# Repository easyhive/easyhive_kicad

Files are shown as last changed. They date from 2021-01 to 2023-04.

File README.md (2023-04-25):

# easyhive_kicad
KiCAD Design Files for easyhive PCB

1. Branch (master): Design with Nb-IoT Modul from ublox (SARA N310)
2. Branch: Design with Nb-IoT Modul from Quectel (BC66 04 Std)

Notes for Generate the bom of material:
1. copy file "easyhive_bom.py" to your local KiCad Plugin folder
e.g. /usr/share/kicad/plugins
2. Open Eeschema
3. Tools -> Generate Bill of Material: add a new plugin (choose easyhive_bom.py)
4. Generate BOM! Path is your KiCad project directory

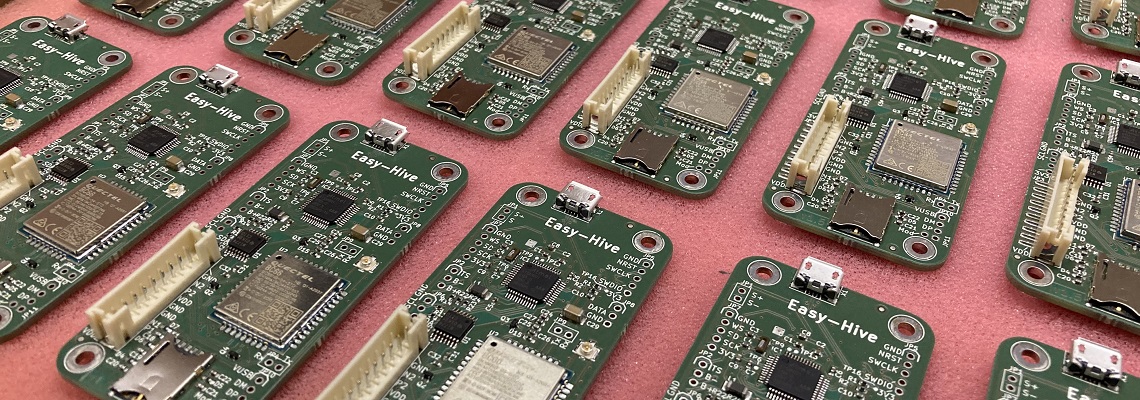
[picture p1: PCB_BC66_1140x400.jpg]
'easyhive PCB board version 1.5'


### copyright
Software: GPL 3.0 and following versions   
Hardware: CERN OHL 1.2 and following versions   
   
This files are distributed in the hope that it will be useful,
but WITHOUT ANY WARRANTY; without even the implied warranty of
MERCHANTABILITY or FITNESS FOR A PARTICULAR PURPOSE.
See the GNU General Public License for more details.

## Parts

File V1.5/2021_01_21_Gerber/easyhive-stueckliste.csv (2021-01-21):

Source: | ~/easyhive_kicad/V1.5/easyhive.sch
Date: | Do 21 Jan 2021 20:41:31 CET
Tool: | Eeschema 5.1.8+dfsg1-1~bpo10+1
Generator: | /usr/share/kicad/plugins/easyhive_bom.py
Component Count: | 86
Ref | Qnty | Value | Package | MPN | Manufacturer | Description
C1, C5, C6, C7, C14, C15, C22, C24, C28, | 9 | 100n | C0402
C2, C11, C30, C31, C32, | 5 | 1u | C0402
C3, C4, C26, | 3 | 15p | C0402
C8, C9, C16, C17, | 4 | 10u | C0402
C10, | 1 | 100p | C0402
C12, C13, C23, | 3 | 4u7 | C0402
C18, C19, C20, C21, | 4 | 47p | C0402
C25, | 1 | 56p | C0402
C27, | 1 | 10n | C0402
C29, | 1 | 100u | 1206 | GRM31CR60J107ME39L | Murata | oder Tantal T490A107M006ATE800
D1, D2, | 2 | MBR0520LT | SOD123 | MBR0520LT | ON Semiconductor | auch anderer Hersteller moeglich
D4, D5, D6, D7, D8, D9, D10, D11, D12, D13, D14, D15, | 12 | PESD0402-140 | 0402-TVS | PESD0402-140 | Littelfuse | auch anderer Hersteller moeglich
F1, | 1 | 6V/0.5A | 1206 | 0ZCJ0050FF2G | Bel Fuse Inc | auch anderer Hersteller moeglich
IC1, | 1 | ATSAMD21G | TQFP48 | TSAMD21G18A-AUT | Microchip Technology
IC2, | 1 | BQ2407X | VQFN16 | BQ24072RGTT | TI
IC3, | 1 | ADS1232 | TSSOP24 | ADS1232IPWR | TI
IC4, | 1 | DS18B20U | UMAX8 | DS18B20U+ | Maxim Integrated
IC5, | 1 | XC6220B331 | SOT25 | XC6220B331MR-G | Torex Semiconductor
IC7, | 1 | TPS22919 | sot-sc70-6 | TPS22919DCKR | TI
J1, | 1 | U.FL | U.FL | U.FL-R-SMT-1(01) | Hirose
JP3, | 1 | JST PH | JST_PH_B10B-PH-SM4-TB_1x10-1MP_P2.00mm_Vertical | PH_B10B-PH-SM4-TB | JST
K1, | 1 | 693043020611 | 693043020611 | 693043020611 | WURTH
L1, L2, | 2 | SM-1206 | SM-1206 | 742792141 | WURTH | auch anderer Hersteller moeglich
P1, | 1 | PKMCS | PKMCS_BUZZER | PKMCS0909E4000-R1 | Murata
Q1, | 1 | 32768 Hz | FC135
Q2, Q3, Q4, | 3 | DTC123JET1G | SC75_SOT416 | DTC123JET1G | ON Semiconductor | auch anderer Hersteller moeglich
R1, | 1 | 330 | C0402
R2, | 1 | 2k2 | C0402
R3, R22, R23, R24, | 4 | 0R | C0402
R4, | 1 | 1k18 | C0402
R5, | 1 | 680R | C0402
R6, R10, | 2 | 10K | C0402
R7, R8, R9, | 3 | 22R | C0402
R13, R14, | 2 | 2k | C0402
R15, | 1 | NTC 103AT | C0402 | ABNTC-0402-103J-4050F-T | Abracon | auch anderer Hersteller moeglich
R16, | 1 | 4M7 | C0402
R17, | 1 | 10M | C0402
R18, | 1 | 4k7 | C0402
R25, | 1 | 1M | C0402
U1, | 1 | SN74AVC4T774PWG4 | PW16 | SN74AVC4T774PWG4 | TI
U2, | 1 | BC66 | Quectel_BC66 |  | Quectel
X1, | 1 | USB_MICRO_SHIELD | USBMICRO | 10118193-0001LF | Amphenol ICC

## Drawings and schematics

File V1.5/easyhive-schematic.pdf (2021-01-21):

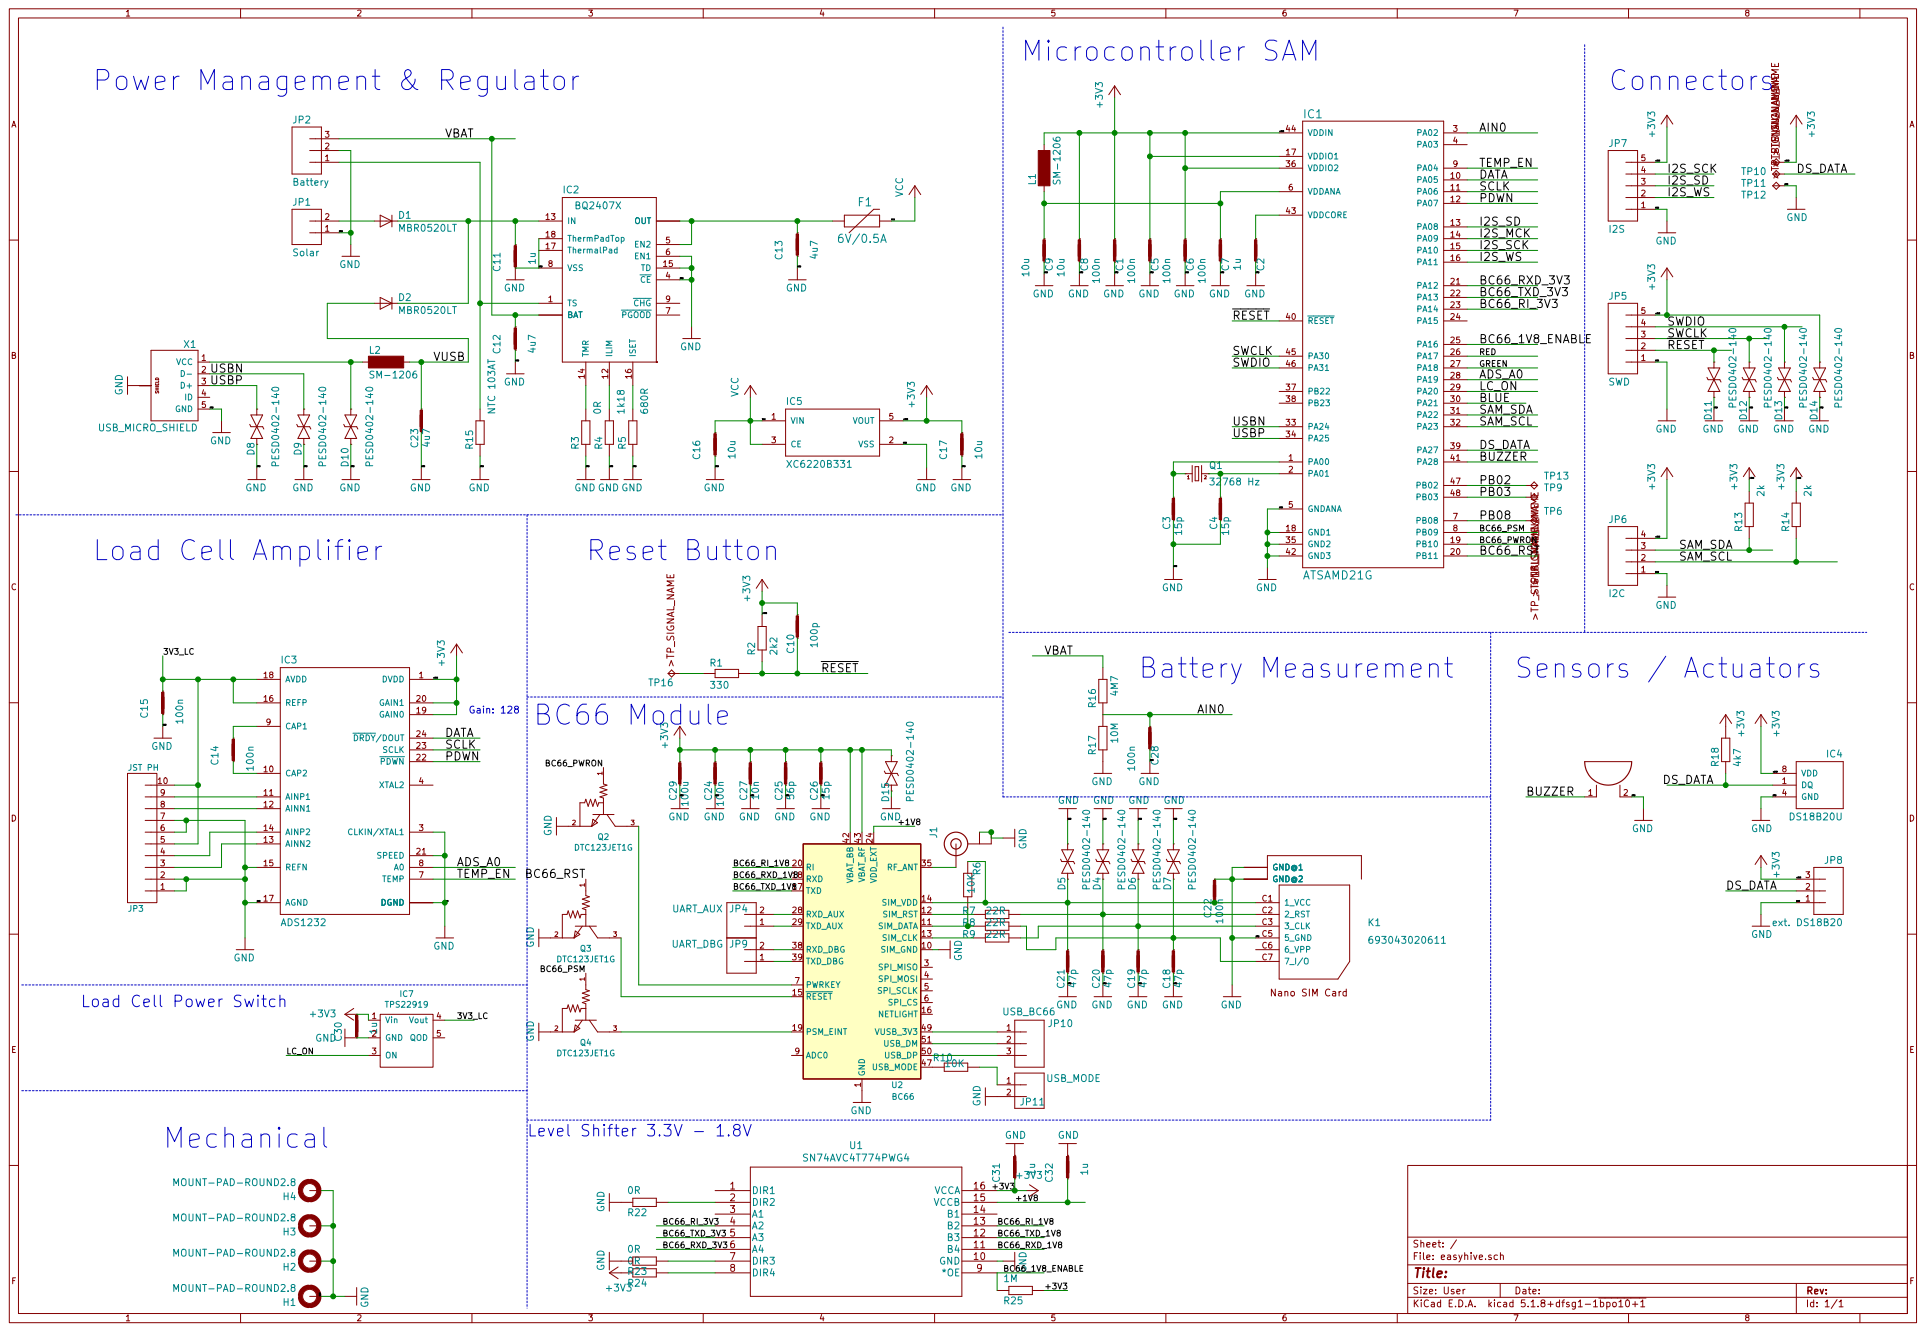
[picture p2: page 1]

1 SIM_GND 10 SIM_DATA 11 SIM_RST 12 SIM_CLK 13 SIM_VDD 14 RESET 15 NETLIGHT 16 TXD 17 RXD 18 PSM_EINT 19 RI 20 VDD_EXT 24 RXD_AUX 28 TXD_AUX 29 SPI_MISO 3 RF_ANT 35 RXD_DBG 38 TXD_DBG 39 SPI_MOSI 4 VBAT_BB 42 VBAT_RF 43 USB_MODE 47 VUSB_3V3 49 SPI_SCLK 5 USB_DP 50 USB_DM 51 SPI_CS 6 PWRKEY 7 ADC0 9 U2BC66 +3V3 GND GND

1 GND

I2S_MCK

2_RST C2
3_CLK C3
GND | 5_GND C5

Load Cell Power Switch

File: easyhive.sch Sheet: /

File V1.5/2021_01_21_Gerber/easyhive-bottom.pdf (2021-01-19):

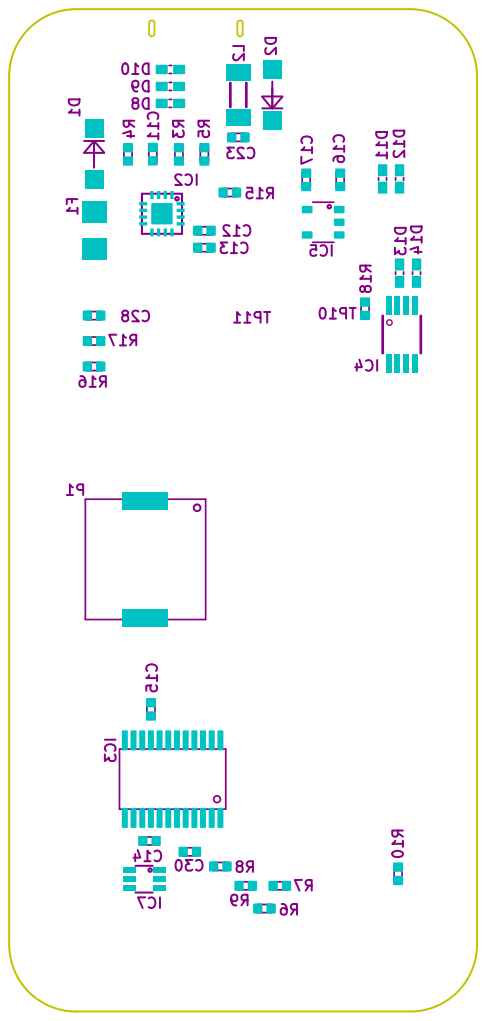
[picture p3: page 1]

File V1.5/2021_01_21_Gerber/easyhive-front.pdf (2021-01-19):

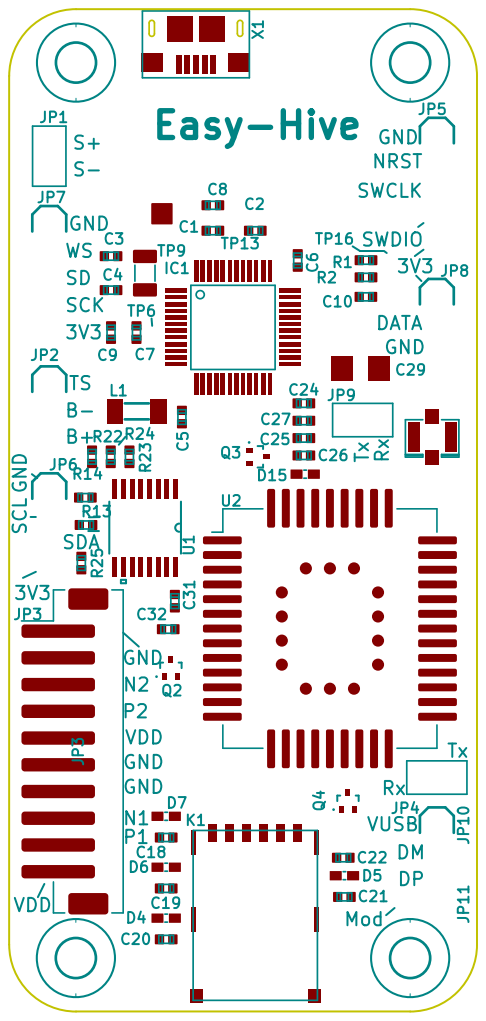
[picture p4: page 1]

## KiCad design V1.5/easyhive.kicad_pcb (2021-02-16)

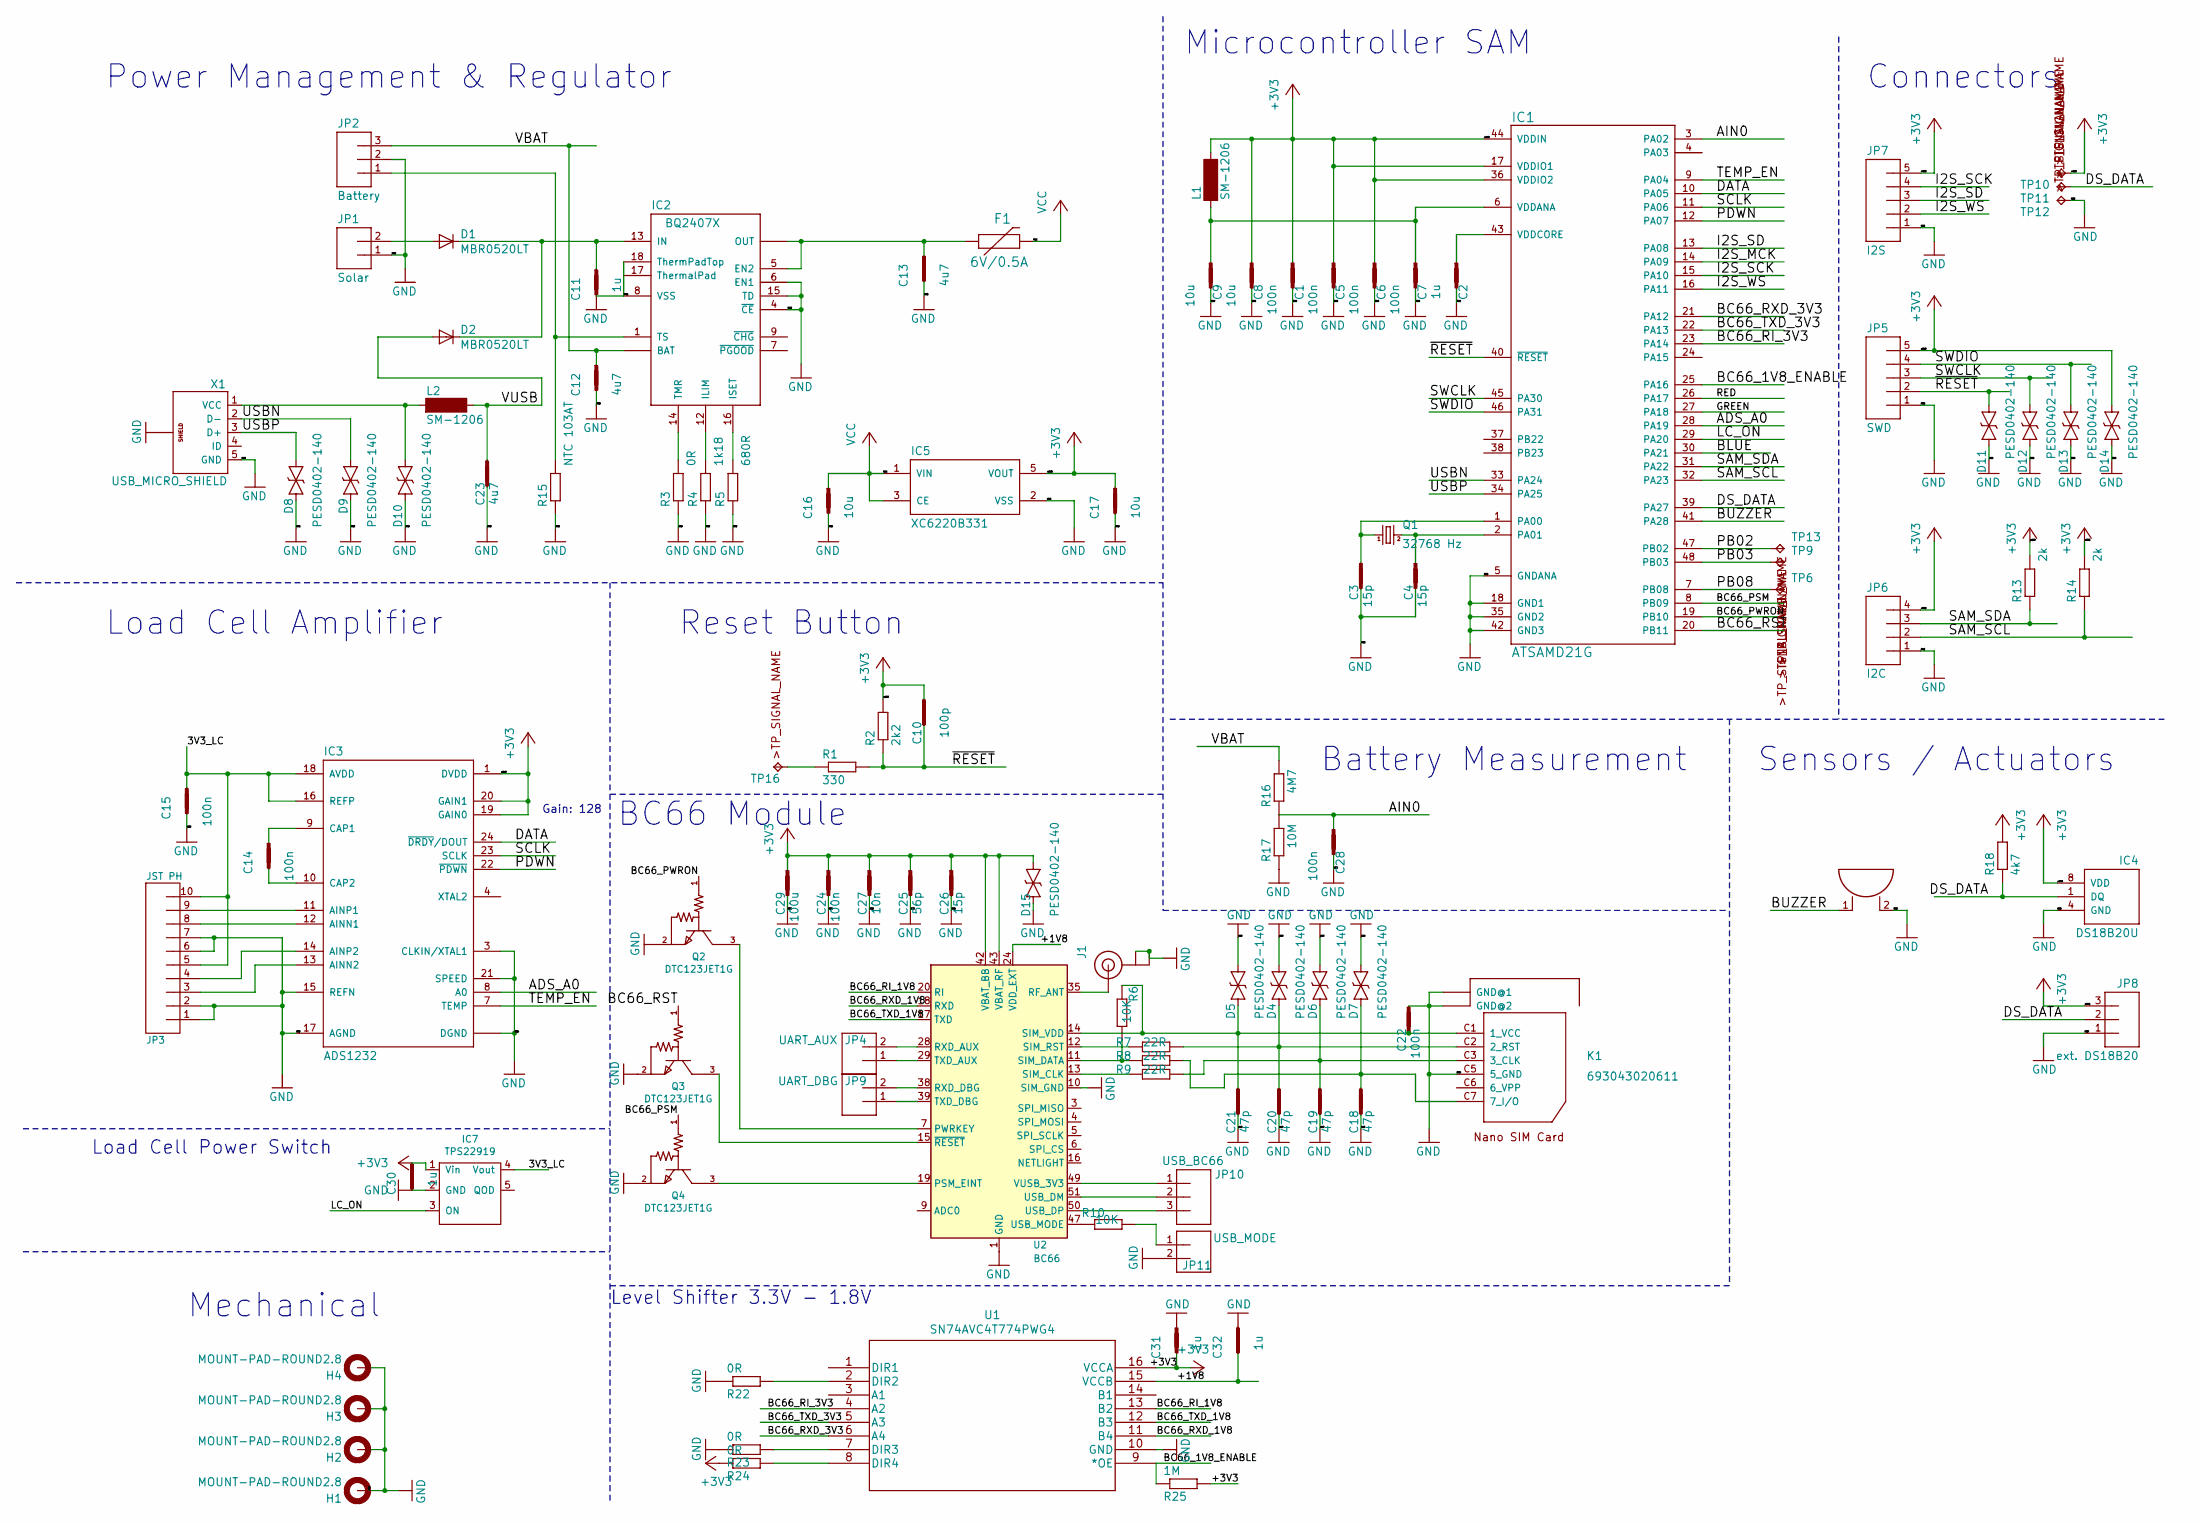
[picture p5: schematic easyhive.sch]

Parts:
C1, C5, C6, C7, C14, C15, C22, C24, C28: 100n; C0402
C2, C11, C30, C31, C32: 1u; C0402
C3, C4, C26: 15p; C0402
C8, C9, C16, C17: 10u; C0402
C10: 100p; C0402
C12, C13, C23: 4u7; C0402
C18, C19, C20, C21: 47p; C0402
C25: 56p; C0402
C27: 10n; C0402
C29: 100u; 1206; MPN GRM31CR60J107ME39L
D1, D2: MBR0520LT; SOD123; MPN MBR0520LT
D4, D5, D6, D7, D8, D9, D10, D11, D12, D13, D14, D15: PESD0402-140; 0402-TVS; MPN PESD0402-140
F1: 6V/0.5A; 1206; MPN 0ZCJ0050FF2G
H1, H2, H3, H4: MOUNT-PAD-ROUND2.8; 2,8-PAD
IC1: ATSAMD21G; TQFP48; MPN TSAMD21G18A-AUT
IC2: BQ2407X; VQFN16; MPN BQ24072RGTT
IC3: ADS1232; TSSOP24; MPN ADS1232IPWR
IC4: DS18B20U; UMAX8; MPN DS18B20U+
IC5: XC6220B331; SOT25; MPN XC6220B331MR-G
IC7: TPS22919; sot-sc70-6; MPN TPS22919DCKR
J1: U.FL; MPN U.FL-R-SMT-1(01)
JP1: Solar; 1X02_2MM_klein
JP2: Battery; 1X03-2MM_klein
JP3: JST PH; JST_PH_B10B-PH-SM4-TB_1x10-1MP_P2.00mm_Vertical; MPN PH_B10B-PH-SM4-TB
JP4: UART_AUX; 1X02_2MM_klein
JP5: SWD; 1X05-2MM_klein
JP6: I2C; 1X04-2MM_klein
JP7: I2S; 1X05-2MM_klein
JP8: ext. DS18B20; 1X03-2MM_re_klein
JP9: UART_DBG; 1X02_2MM_klein
JP10: USB_BC66; 1X03-2MM_klein
JP11: USB_MODE; 1X02_2MM_klein
K1: 693043020611; MPN 693043020611
L1, L2: SM-1206; MPN 742792141
P1: PKMCS; PKMCS_BUZZER; MPN PKMCS0909E4000-R1
Q1: 32768 Hz; FC135
Q2, Q3, Q4: DTC123JET1G; SC75_SOT416; MPN DTC123JET1G
R1: 330; C0402
R2: 2k2; C0402
R3, R22, R23, R24: 0R; C0402
R4: 1k18; C0402
R5: 680R; C0402
R6, R10: 10K; C0402
R7, R8, R9: 22R; C0402
R13, R14: 2k; C0402
R15: NTC 103AT; C0402; MPN ABNTC-0402-103J-4050F-T
R16: 4M7; C0402
R17: 10M; C0402
R18: 4k7; C0402
R25: 1M; C0402
TP6, TP9, TP10, TP11, TP12, TP13, TP16: TPTP08R; TP08R
U1: SN74AVC4T774PWG4; PW16; MPN SN74AVC4T774PWG4
U2: BC66; Quectel_BC66
X1: USB_MICRO_SHIELD; USBMICRO; MPN 10118193-0001LF

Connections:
+3V3: C1.1, C5.1, C6.1, C8.1, C10.1, C17.1, C24.1, C25.1, C26.1, C27.1, C29.1, C30.1, C31.2, D14.P$2 (C), D15.P$2 (C), IC1.17 (VDDIO1), IC1.36 (VDDIO2), IC1.44 (VDDIN), IC3.1 (DVDD), IC3.19 (GAIN0), IC3.20 (GAIN1), IC4.8 (VDD), IC5.5 (VOUT), IC7.1 (Vin), JP5.5, JP6.4, JP7.5, JP8.3, L1.2, R2.2, R13.2, R14.2, R18.2, R24.1, R25.2, TP10.TP, U1.16 (VCCA), U2.42 (VBAT_BB), U2.43 (VBAT_RF)
/3V3_LC: C15.1, IC3.16 (REFP), IC3.18 (AVDD), IC7.4 (Vout), JP3.5, JP3.10
/+1V8: C32.2, U1.15 (VCCB), U2.24 (VDD_EXT)
/ADS_A0: IC1.28 (PA19), IC3.8 (A0)
/AIN0: C28.1, IC1.3 (PA02), R16.1, R17.2
/BC66_1V8_ENABLE: IC1.25 (PA16), R25.1, U1.9 (*OE)
/BC66_PSM: IC1.8 (PB09), Q4.1 (B)
/BC66_PWRON: IC1.19 (PB10), Q2.1 (B)
/BC66_RI_1V8: U1.13 (B2), U2.20 (RI)
/BC66_RI_3V3: IC1.23 (PA14), U1.4 (A2)
/BC66_RST: IC1.20 (PB11), Q3.1 (B)
/BC66_RXD_1V8: U1.11 (B4), U2.18 (RXD)
/BC66_RXD_3V3: IC1.21 (PA12), U1.6 (A4)
/BC66_TXD_1V8: U1.12 (B3), U2.17 (TXD)
/BC66_TXD_3V3: IC1.22 (PA13), U1.5 (A3)
/BLUE: IC1.30 (PA21)
/BUZZER: IC1.41 (PA28), P1.1
/DATA: IC1.10 (PA05), IC3.24 (~DRDY~/DOUT)
/DS_DATA: IC1.39 (PA27), IC4.1 (DQ), JP8.2, R18.1, TP11.TP
/GREEN: IC1.27 (PA18)
/I2S_MCK: IC1.14 (PA09)
/I2S_SCK: IC1.15 (PA10), JP7.4
/I2S_SD: IC1.13 (PA08), JP7.3
/I2S_WS: IC1.16 (PA11), JP7.2
/LC_ON: IC1.29 (PA20), IC7.3 (ON)
/PB02: IC1.47 (PB02), TP13.TP
/PB03: IC1.48 (PB03), TP9.TP
/PB08: IC1.7 (PB08), TP6.TP
/PDWN: IC1.12 (PA07), IC3.22 (~PDWN)
/RED: IC1.26 (PA17)
/SAM_SCL: IC1.32 (PA23), JP6.2, R14.1
/SAM_SDA: IC1.31 (PA22), JP6.3, R13.1
/SCLK: IC1.11 (PA06), IC3.23 (SCLK)
/SWCLK: D12.P$2 (C), IC1.45 (PA30), JP5.3
/SWDIO: D13.P$2 (C), IC1.46 (PA31), JP5.4
/TEMP_EN: IC1.9 (PA04), IC3.7 (TEMP)
/USBN: D9.P$2 (C), IC1.33 (PA24), X1.2 (D-)
/USBP: D8.P$2 (C), IC1.34 (PA25), X1.3 (D+)
/VBAT: C12.1, IC2.2 (BAT), IC2.3 (BAT), JP2.3, R16.2
/VUSB: C23.1, D2.A, L2.2
/~RESET: C10.2, D11.P$2 (C), IC1.40 (~RESET), JP5.2, R1.2, R2.1
GND: C1.2, C2.2, C3.2, C4.2, C5.2, C6.2, C7.2, C8.2, C9.2, C11.2, C12.2, C13.2, C15.2, C16.2, C17.2, C18.2, C19.2, C20.2, C21.2, C22.1, C23.2, C24.2, C25.2, C26.2, C27.2, C28.2, C29.2, C30.2, C31.1, C32.1, D4.P$2 (C), D5.P$2 (C), D6.P$2 (C), D7.P$2 (C), D8.P$1 (A), D9.P$1 (A), D10.P$1 (A), D11.P$1 (A), D12.P$1 (A), D13.P$1 (A), D14.P$1 (A), D15.P$1 (A), H1.B2,8, H2.B2,8, H3.B2,8, H4.B2,8, IC1.5 (GNDANA), IC1.18 (GND1), IC1.35 (GND2), IC1.42 (GND3), IC2.4 (~CE), IC2.6 (EN1), IC2.8 (VSS), IC2.15 (TD), IC2.18 (TERMAL), IC3.2 (DGND), IC3.3 (CLKIN/XTAL1), IC3.5 (DGND), IC3.6 (DGND), IC3.15 (REFN), IC3.17 (AGND), IC3.21 (SPEED), IC4.4 (GND), IC5.2 (VSS), IC7.2 (GND), J1.P$1 (GND@0), J1.P$2 (GND@1), JP1.1, JP2.2, JP3.1, JP3.2, JP3.6, JP3.7, JP5.1, JP6.1, JP7.1, JP8.1, JP11.2, K1.C5 (5_GND), K1.Z1 (GND@1), K1.Z2 (GND@1), K1.Z3 (GND@1), K1.Z4 (GND@2), K1.Z5 (GND@2), K1.Z6 (GND@2), P1.2, Q2.2 (E), Q3.2 (E), Q4.2 (E), R3.1, R4.1, R5.1, R15.1, R17.1, R22.1, R23.1, U1.10 (GND), U2.1 (GND), U2.10 (SIM_GND), U2.27 (GND), U2.34 (GND), U2.36 (GND), U2.37 (GND), U2.40 (GND), U2.41 (GND), X1.5 (GND), X1.S1 (SHIELD), X1.S2 (SHIELD), X1.S3 (SHIELD), X1.S4 (SHIELD), X1.S5 (SHIELD), X1.S6 (SHIELD)
unnamed: C2.1, IC1.43 (VDDCORE)
unnamed: C3.1, IC1.1 (PA00), Q1.1
unnamed: C4.1, IC1.2 (PA01), Q1.2
unnamed: C7.1, C9.1, IC1.6 (VDDANA), L1.1
unnamed: C11.1, D1.C, D2.C, IC2.13 (IN)
unnamed: C13.1, F1.1, IC2.5 (EN2), IC2.10 (OUT), IC2.11 (OUT)
unnamed: C14.1, IC3.9 (CAP1)
unnamed: C14.2, IC3.10 (CAP2)
unnamed: C18.1, D7.P$1 (A), K1.C7 (7_I/O), R8.2
unnamed: C19.1, D6.P$1 (A), K1.C3 (3_CLK), R9.2
unnamed: C20.1, D4.P$1 (A), K1.C2 (2_RST), R7.2
unnamed: C21.1, C22.2, D5.P$1 (A), K1.C1 (1_VCC), R6.1, U2.14 (SIM_VDD)
unnamed: D1.A, JP1.2
unnamed: D10.P$2 (C), L2.1, X1.1 (VCC)
unnamed: IC2.1 (TS), JP2.1, R15.2
unnamed: IC2.12 (ILIM), R4.2
unnamed: IC2.14 (TMR), R3.2
unnamed: IC2.16 (ISET), R5.2
unnamed: IC2.17 (TERMAL), IC2.18 (TERMAL), IC2.V1 (TERMAL), IC2.V2 (TERMAL), IC2.V3 (TERMAL), IC2.V4 (TERMAL)
unnamed: IC3.11 (AINP1), JP3.9
unnamed: IC3.12 (AINN1), JP3.8
unnamed: IC3.13 (AINN2), JP3.3
unnamed: IC3.14 (AINP2), JP3.4
unnamed: J1.P$3 (SIGNAL), U2.35 (RF_ANT)
unnamed: JP4.1, U2.29 (TXD_AUX)
unnamed: JP4.2, U2.28 (RXD_AUX)
unnamed: JP9.1, U2.39 (TXD_DBG)
unnamed: JP9.2, U2.38 (RXD_DBG)
unnamed: JP10.1, U2.49 (VUSB_3V3)
unnamed: JP10.2, U2.51 (USB_DM)
unnamed: JP10.3, U2.50 (USB_DP)
unnamed: JP11.1, R10.2
unnamed: Q2.3 (C), U2.7 (PWRKEY)
unnamed: Q3.3 (C), U2.15 (~RESET)
unnamed: Q4.3 (C), U2.19 (PSM_EINT)
unnamed: R1.1, TP16.TP
unnamed: R6.2, R8.1, U2.11 (SIM_DATA)
unnamed: R7.1, U2.12 (SIM_RST)
unnamed: R9.1, U2.13 (SIM_CLK)
unnamed: R10.1, U2.47 (USB_MODE)
unnamed: R22.2, U1.2 (DIR2)
unnamed: R23.2, U1.7 (DIR3)
unnamed: R24.2, U1.8 (DIR4)
VCC: C16.1, F1.2, IC5.1 (VIN), IC5.3 (CE)

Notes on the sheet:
Gain: 128
Power Management & Regulator
Microcontroller SAM
BC66 Module
Load Cell Amplifier
Connectors
Sensors / Actuators
Mechanical
Reset Button
Battery Measurement
Load Cell Power Switch
Level Shifter 3.3V - 1.8V

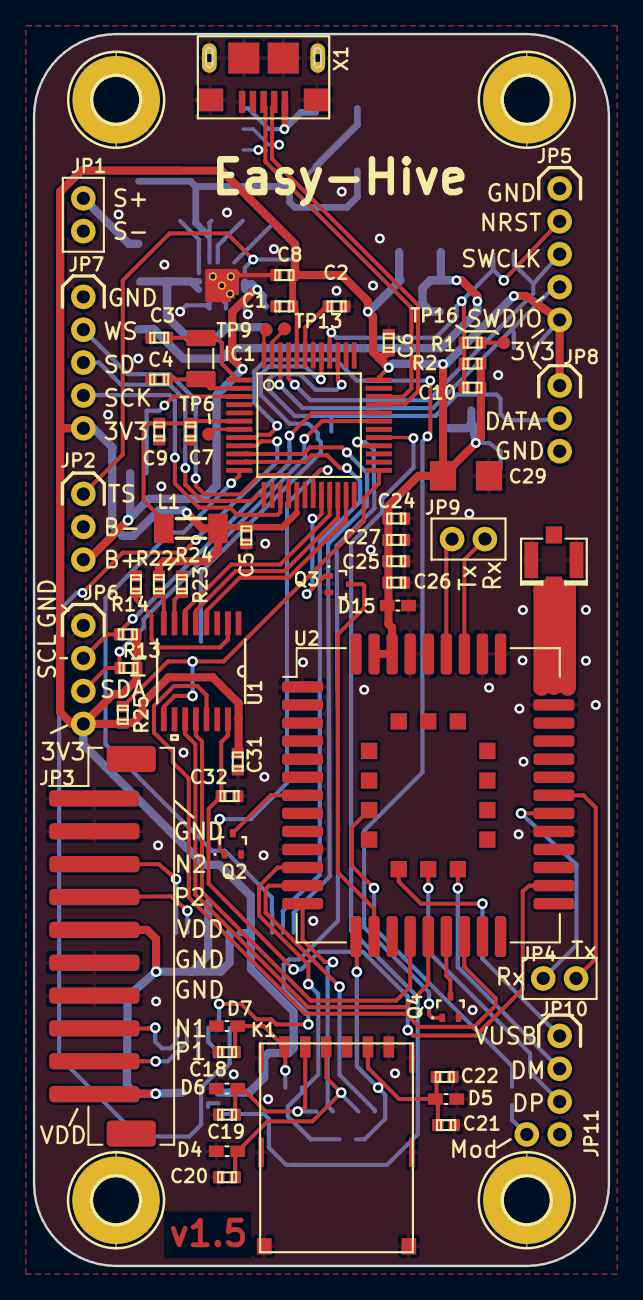
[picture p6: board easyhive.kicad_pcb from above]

Board: 2 copper layers, 35.0 x 75.0 mm, 106 parts (0 on the bottom side), 82 nets.

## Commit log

2020-12-30 Original V1.4 2020_04_29
    [sodaq_sff.cfg]
2020-12-30 v0.2 fixed BoardId
    fixed boardID 47 and send freemem instead of battery voltage (in sktech.ino)
2020-12-30 v0.3 without fixed BoardID
    without fixed BoardID
    delete void LEDs in Easyhive.h
2020-12-30 v0.4 fix BoardID
2021-01-01 loops commentiert und break hinzugefuegt - datenpakete speichern, wenn server nicht erreichbar ist
2021-01-02 v1.5 PCB SARA N310
    PreVersion for Oertel Gera
    -add 2x DTC123JET1G for PWR_ON + RESET_N
    -add/change capacitors for VCC N310 (recommend in N2/N3 Integration manaual from uBlox)
    -2x Pads TxD/RxD FT for updates
    [easyhive-B_Fab.gbr, easyhive-B_Mask.gbr, easyhive-B_Paste.gbr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]
2021-01-07 only visualization
    remove tracks from LED1 + LED2
    [easyhive-B_Fab.gbr, easyhive-B_Mask.gbr, easyhive-B_Paste.gbr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]
2021-01-09 print out lengthSent (in easyhive.cpp) and only return success if it is > 0
2021-01-13 changed Footprints IC2, Q2,Q3,X1 to SMD
    [easyhive.kicad_pcb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]
2021-01-14 only visualization
    -add Point to footprints U1, IC7, P1, D1, D2
    -move TP1 (hidden by U1)
    [easyhive-B_Fab.gbr, easyhive-B_Mask.gbr, easyhive-B_Paste.gbr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]
2021-01-16 clean easyhive_kicad
    [easyhive_1_3-B.Mask.gbr, easyhive_1_3-B.Paste.gbr, easyhive_1_3-B.SilkS.gbr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]
2021-01-17 v1.5 Oertel
    Realease send to Oertel 04.01.2021
    [easyhive-B_Fab.gbr, easyhive-B_Mask.gbr, easyhive-B_Paste.gbr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]
2021-01-17 v1.5 Oertel with optimizations
    -fixed problems/questions from Oertel
    [easyhive-B_Fab.gbr, easyhive-B_Mask.gbr, easyhive-B_Paste.gbr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]
2021-01-17 schematic quectel
    first draft schematic
    [easyhive-B_Fab.gbr, easyhive-B_Mask.gbr, easyhive-B_Paste.gbr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]
2021-01-17 Begin Routing
    [easyhive.kicad_pcb, easyhive.sch]
2021-01-17 add stueckliste.csv
    [easyhive_stueckliste.csv]
2021-01-18 try to route...
    DRC Checker meckert wegen Bauteilüberschneidung. BC66 hat im Footprint mega Rahmen... Laut Description ist es 17,7mm breit, der Rahmen hat aber über 20mm...
    [easyhive.kicad_pcb]
2021-01-19 Routing done. Need double check and move Silk
    [easyhive.kicad_pcb]
2021-01-19 Need verification.
    -Routing done
    -Silk done
    -USB Mode 2 drill Pads + R10k
    -open review
    [easyhive-B_Fab.gbr, easyhive-B_Mask.gbr, easyhive-B_Paste.gbr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]
2021-01-21 Add schmematic.pdf
    -add easyhive-schematic.pdf
    -rename C22 from 100nF to 100n
    -remove text from JST PH Footprint
    [easyhive-B_Fab.gbr, easyhive-B_Mask.gbr, easyhive-B_Paste.gbr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]
2021-01-22 Track witdh antenna
    [easyhive-B_Fab.gbr, easyhive-B_Mask.gbr, easyhive-B_Paste.gbr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]
2021-02-16 Plugin to generate the BOM
2021-02-16 Add *.drl Files
    [easyhive.kicad_pcb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]
2023-04-25 Update README.md by adding PCB image
